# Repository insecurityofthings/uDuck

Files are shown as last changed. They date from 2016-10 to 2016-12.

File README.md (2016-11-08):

# μDuck

μDuck is stealth HID injector. It's a very small USB device that acts like a scripted keyboard. This can be used for automation and lulz, and has obvious security implications. It's quite similar in functionality to the [Hak5 Rubber Ducky](https://hakshop.com/products/usb-rubber-ducky-deluxe), and even uses the [same syntax](https://github.com/hak5darren/USB-Rubber-Ducky/wiki/Payloads) to define the scripted input.

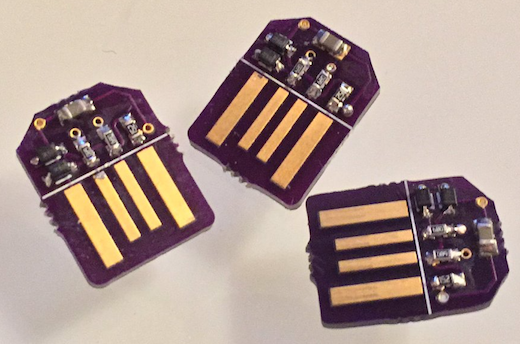
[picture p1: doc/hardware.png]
μDuck hardware


When μDuck is connected, it will wait 2 seconds in programming mode before switching to a keyboard. This is to allow the payload to be updated with the Python tool provided. It will wait 5 seconds before the first HID injection, then retry the payload automatically at 60 seconds, 5 minutes, and then every 4 hours with +/- 1 hour of random variance. This ensures reliable delivery, but expect that your payload may run more than once.

## Building a μDuck

The μDuck is quite inexpensive -- all the parts cost around $2 per unit. However, you will need some tools and know-how to get started. For more information, see the README file in the doc directory.

## Credits and License

The hardware is borrowed from [this blog](http://www.morethantechnical.com/2015/08/03/smallest-attiny45-usb/). The software is a modified version of "CapsLocker", which can be [found here](http://macetech.com/blog/?q=node/46). Our customized hardware design can be found in the "hardware" folder.

Our Python code and hardware design is MIT licensed. The USB firmware is licensed [according to the terms](https://www.obdev.at/products/vusb/license.html) of Objective Development's vUSB and GPLv2.

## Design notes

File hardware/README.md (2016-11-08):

Fixes
=====

- Schematic shows a 2k resistor. Use 1.5k instead.
- See [the documentation](https://github.com/phikshun/uDuck/tree/master/doc) for suggested parts.

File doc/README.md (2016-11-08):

# Building a μDuck

## Tools and Prerequisites

You'll need to following tools to construct the device:

- A decent temperature-controlled soldering iron with a fine point tip
- Solder (lead-free 0.8 mm)
- Flux with a fine-tip applicator
- Magnifying lamp
- A "third hand" tool
- Fine tweezers for handling SMT components
- An AVR programmer or a spare Arduino board
- A SOIC-8 clip for the programmer (not a hard requirement, but makes things much easier)

This project involves SMT soldering. You can find good tutorials [here](https://learn.adafruit.com/adafruit-guide-excellent-soldering/tools) and [here](https://www.sparkfun.com/tutorials/category/2). You'll need steady hands, good lighting, and magnification.

## Order Components

You can order the surface mount components from [DigiKey](http://www.digikey.com). You'll need the following components for each μDuck board:

- 1 x 0.1 uF ceramic capacitor [Link](http://www.digikey.ca/product-search/en?keywords=311-1141-1-ND)
- 2 x 68 Ohm resistors [Link](http://www.digikey.ca/product-search/en?keywords=P68GCT-ND)
- 2 x 3.6V zener diodes [Link](http://www.digikey.ca/product-search/en?keywords=MM3Z3V6T1GOSCT-ND)
- 1 x 1.5K Ohm resistor [Link](http://www.digikey.ca/product-search/en?keywords=311-1.5KGRCT-ND)
- 1 x Atmel ATTiny85 [Link](http://www.digikey.ca/product-search/en?keywords=ATTINY85-20SU-ND)

Note that you can swap components for similar parts with the same electrical properties and form factor.

In addition to the SMT parts, you will also need to get PCBs manufactured. There are many online services that allow you to submit designs and have them shipped to your door, even in fairly small quantities.

When submitting the hardware design, keep in mind the following:

- The board thickness should be 2.4mm. Typical PCB thickness (1.6mm) will fall right out of the port.
- Spring for gold plated pads - it will protect the USB pins from oxidation.

Unfortunately OSH Park cannot do 2.4mm boards, so we're using [AllPCB](http://www.allpcb.com) instead. If you have another preferred manufacturer, the results should be the same.

## Assembly

Use the hardware design files to show you where to place the parts. For IC and diode components, orientation is important. For passive components, they only need to be facing upwards.

Follow the tutorials on SMT soldering, or find a video on Youtube that demonstrates SMT soldering. Remember to use flux! :)

## Programming

There are two steps to programming. First, you'll need to get a bootloader on the microcontroller. Once the bootloader is installed you can upload new payloads with the `uduck_upload.py` script.

If you don't have a dedicated AVR programmer and would like to use an Arduino (this is how the Makefiles are currently setup), follow the instructions found [here](http://www.instructables.com/id/Turn-Your-Arduino-Into-an-ISP/).

### Bootloader Programming

You can find our slightly customized version of Micronucleus [here](https://github.com/phikshun/micronucleus). All we've done is configured the correct parameters in `firmware/configuration/t85_default/bootloaderconfig.h`, and updated the Makefile in `firmware/Makefile`.

To upload the bootloader, wire up a [SOIC-8 programming clip](https://www.amazon.com/Signstek-SOIC8-Socket-Adpter-Programmer/dp/B00V9QNAC4) to your AVR programmer and connect to the ATTiny85.

Now modify the following lines in the file `firmware/Makefile`:

Line 25: `PROGRAMMER ?= -c arduino`
- Leave as "arduino" or change to the correct programmer type

Line 29: `AVRDUDE = avrdude $(PROGRAMMER) -p $(DEVICE) -P /dev/cu.usbserial-A8008I9o -b 19200`
- Change the serial port and baud rate to the correct values. If you don't know what serial port your programmer is using, load the Arduino IDE and check.

To upload, you'll need `avrdude` installed. Sparkfun [has a tutorial](https://learn.sparkfun.com/tutorials/pocket-avr-programmer-hookup-guide/using-avrdude) that shows you the basics of AVRDUDE, which should be enough to get you up and running.

Once you have AVRDUDE working, open a shell, cd into the Micronucleus `firmware` directory and enter the commands:

`make fuse`

`make flash`

You don't need a full `avr-gcc` toolchain because we've precompiled the firmware for you. You're welcome to install an AVR toolchain and recompile. This will update the fuse settings on the ATTiny and program the bootloader in flash.

### Uploading the HID Injection Payload

To make it simple to update the μDuck payload, we've built a simple Python script. You will need to install the dependencies first using pip:

`pip install -r requirements.txt`

Before you start the programming tool, disconnect the μDuck from USB. The tool with prompt you when it's ready for the μDuck to be connected to USB.

The upload script takes only one parameter: the name of a file containing your Duckyscript. You can find some example scripts [here](https://github.com/hak5darren/USB-Rubber-Ducky/wiki/Payloads) if you need some inspiration.

Finally, run the command (where ducky.txt is the name of your Duckyscript file):

`./uduck_upload.py ducky.txt`

Your output should look similar to:

```
[+] Successfully compiled duckyscript
[+] Reading firmware image
[+] Patching firmware
[+] Successfully patched firmware

[+] Please plug in your uDuck device...
Press Ctrl-C to terminate the program...
[+] Device found:
      Available space for user applications: 6522 bytes
      Suggested sleep time between sending pages: 5 ms
      Whole page count: 102 page size: 64
      Erase function sleep duration: 510 ms

[+] Erasing flash...
[====================================================================] 100%
[+] Starting upload...
[====================================================================] 100%
[+] Upload finished. Enjoy! ;)
```

Plug-in your device when prompted. As indicated by the output above, the script is byte patching the compiled Duckyscript into the firmware hex file dynamically, then uploading it to the bootloader. We think that's pretty neat.

If you experience an error, let us know by submitting an issue. We will try to assist if time permits.

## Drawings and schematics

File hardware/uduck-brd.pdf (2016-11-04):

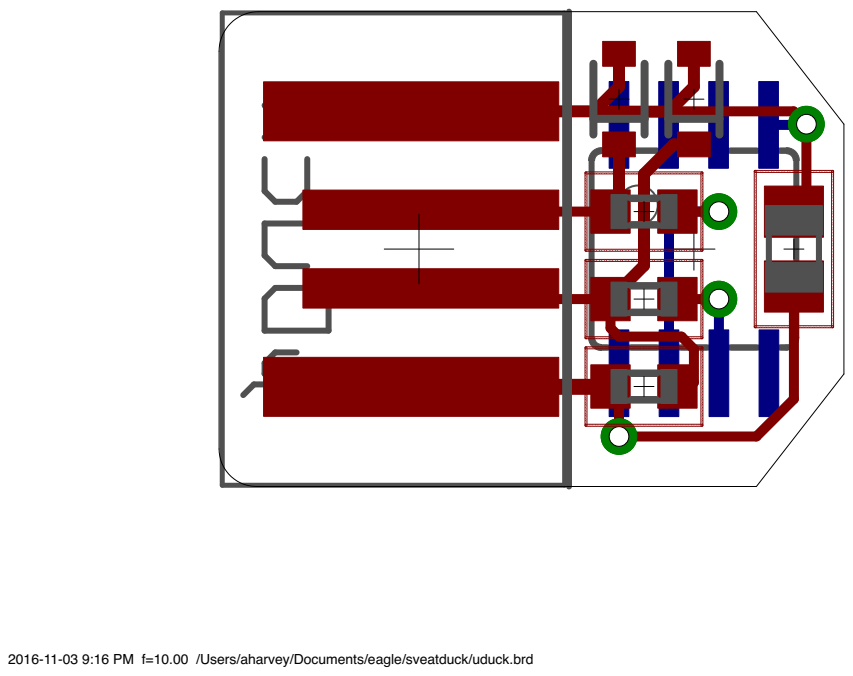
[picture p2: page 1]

2016-11-03 9:16 PM f=10.00 /Users/aharvey/Documents/eagle/sveatduck/uduck.brd

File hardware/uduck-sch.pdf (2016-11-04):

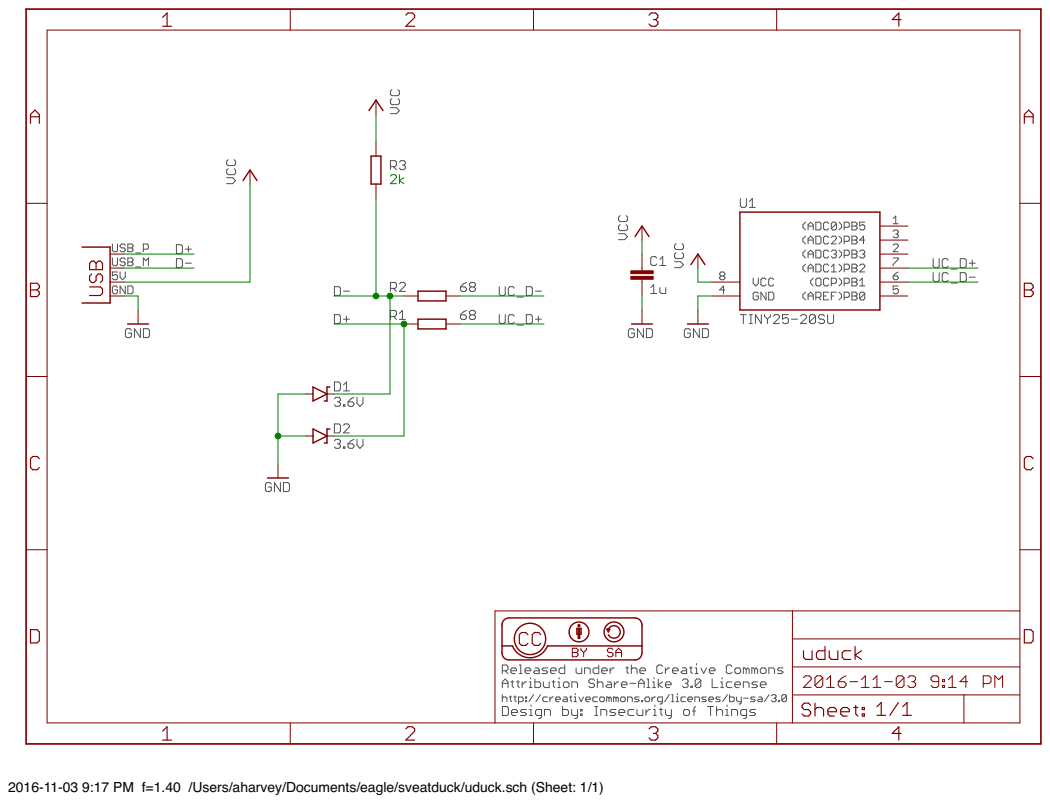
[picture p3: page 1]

2016-11-03 9:17 PM f=1.40 /Users/aharvey/Documents/eagle/sveatduck/uduck.sch (Sheet: 1/1)

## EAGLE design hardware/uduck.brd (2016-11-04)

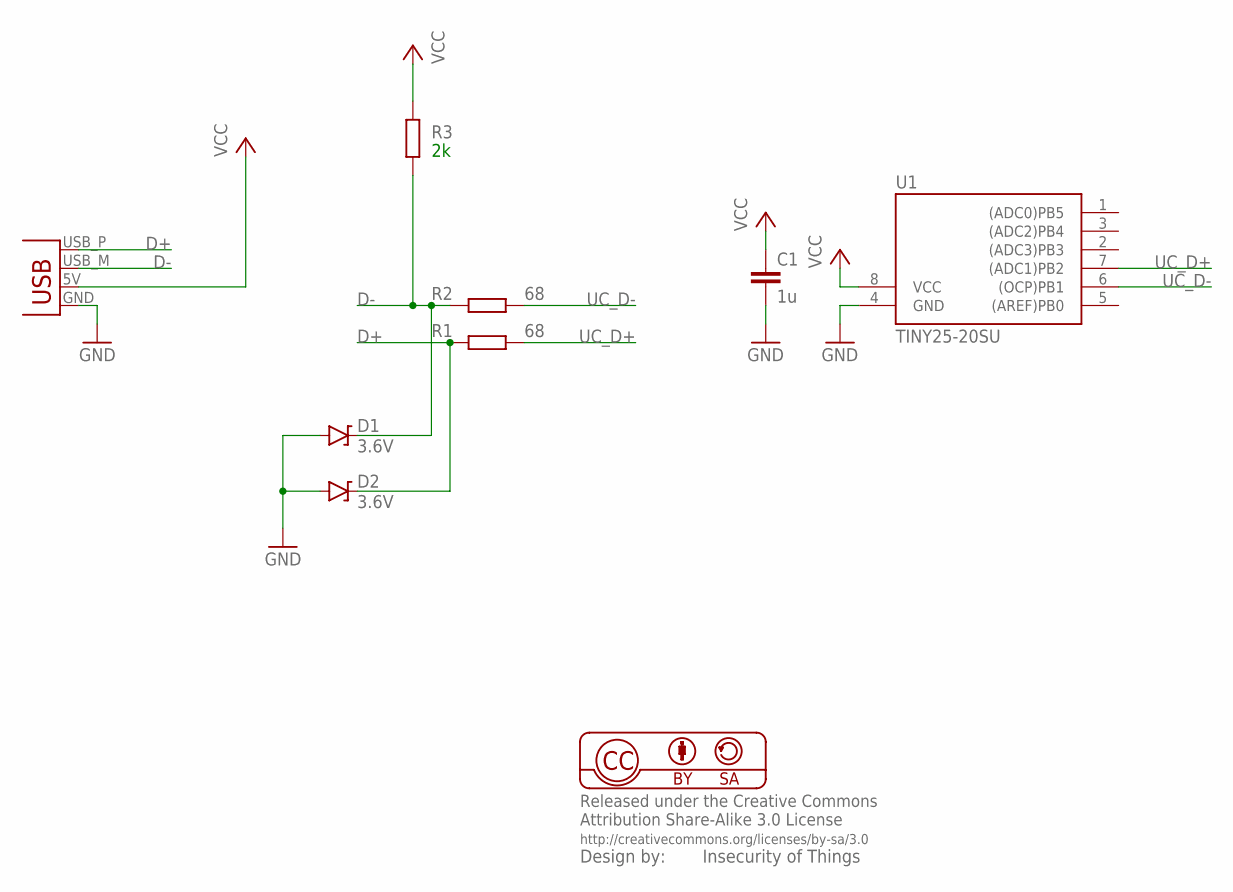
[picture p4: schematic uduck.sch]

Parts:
C1: 1u; C0805
D1, D2: 3.6V; SOD-323
R1, R2: 68; R0603
R3: 2k; R0603
U1: TINY25-20SU; SOIC8
X1: USBPCB; USB-A-PCB

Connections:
D+: D2.C, R1.2, X1.USB_P (D+)
D-: D1.C, R2.2, R3.1, X1.USB_M (D-)
GND: C1.2, D1.A, D2.A, U1.4 (GND), X1.GND
UC_D+: R1.1, U1.7 ((ADC1)PB2)
UC_D-: R2.1, U1.6 ((OCP)PB1)
VCC: C1.1, R3.2, U1.8 (VCC), X1.5V (VBUS)

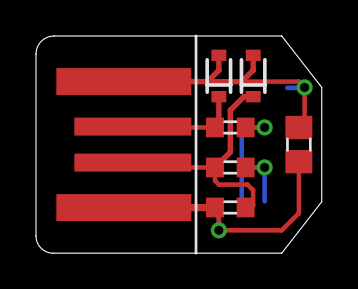
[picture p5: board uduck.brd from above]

Board: 2 copper layers, 15.9 x 12.1 mm, 8 parts (1 on the bottom side), 6 nets.

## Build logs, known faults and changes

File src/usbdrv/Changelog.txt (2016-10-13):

This file documents changes in the firmware-only USB driver for atmel's AVR
microcontrollers. New entries are always appended to the end of the file.
Scroll down to the bottom to see the most recent changes.

2005-04-01:
  - Implemented endpoint 1 as interrupt-in endpoint.
  - Moved all configuration options to usbconfig.h which is not part of the
    driver.
  - Changed interface for usbVendorSetup().
  - Fixed compatibility with ATMega8 device.
  - Various minor optimizations.

2005-04-11:
  - Changed interface to application: Use usbFunctionSetup(), usbFunctionRead()
    and usbFunctionWrite() now. Added configuration options to choose which
    of these functions to compile in.
  - Assembler module delivers receive data non-inverted now.
  - Made register and bit names compatible with more AVR devices.

2005-05-03:
  - Allow address of usbRxBuf on any memory page as long as the buffer does
    not cross 256 byte page boundaries.
  - Better device compatibility: works with Mega88 now.
  - Code optimization in debugging module.
  - Documentation updates.

2006-01-02:
  - Added (free) default Vendor- and Product-IDs bought from voti.nl.
  - Added USBID-License.txt file which defines the rules for using the free
    shared VID/PID pair.
  - Added Readme.txt to the usbdrv directory which clarifies administrative
    issues.

2006-01-25:
  - Added "configured state" to become more standards compliant.
  - Added "HALT" state for interrupt endpoint.
  - Driver passes the "USB Command Verifier" test from usb.org now.
  - Made "serial number" a configuration option.
  - Minor optimizations, we now recommend compiler option "-Os" for best
    results.
  - Added a version number to usbdrv.h

2006-02-03:
  - New configuration variable USB_BUFFER_SECTION for the memory section where
    the USB rx buffer will go. This defaults to ".bss" if not defined. Since
    this buffer MUST NOT cross 256 byte pages (not even touch a page at the
    end), the user may want to pass a linker option similar to
    "-Wl,--section-start=.mybuffer=0x800060".
  - Provide structure for usbRequest_t.
  - New defines for USB constants.
  - Prepared for HID implementations.
  - Increased data size limit for interrupt transfers to 8 bytes.
  - New macro usbInterruptIsReady() to query interrupt buffer state.

2006-02-18:
  - Ensure that the data token which is sent as an ack to an OUT transfer is
    always zero sized. This fixes a bug where the host reports an error after
    sending an out transfer to the device, although all data arrived at the
    device.
  - Updated docs in usbdrv.h to reflect changed API in usbFunctionWrite().

* Release 2006-02-20

  - Give a compiler warning when compiling with debugging turned on.
  - Added Oleg Semyonov's changes for IAR-cc compatibility.
  - Added new (optional) functions usbDeviceConnect() and usbDeviceDisconnect()
    (also thanks to Oleg!).
  - Rearranged tests in usbPoll() to save a couple of instructions in the most
    likely case that no actions are pending.
  - We need a delay between the SET ADDRESS request until the new address
    becomes active. This delay was handled in usbPoll() until now. Since the
    spec says that the delay must not exceed 2ms, previous versions required
    aggressive polling during the enumeration phase. We have now moved the
    handling of the delay into the interrupt routine.
  - We must not reply with NAK to a SETUP transaction. We can only achieve this
    by making sure that the rx buffer is empty when SETUP tokens are expected.
    We therefore don't pass zero sized data packets from the status phase of
    a transfer to usbPoll(). This change MAY cause troubles if you rely on
    receiving a less than 8 bytes long packet in usbFunctionWrite() to
    identify the end of a transfer. usbFunctionWrite() will NEVER be called
    with a zero length.

* Release 2006-03-14

  - Improved IAR C support: tiny memory model, more devices
  - Added template usbconfig.h file under the name usbconfig-prototype.h

* Release 2006-03-26

  - Added provision for one more interrupt-in endpoint (endpoint 3).
  - Added provision for one interrupt-out endpoint (endpoint 1).
  - Added flowcontrol macros for USB.
  - Added provision for custom configuration descriptor.
  - Allow ANY two port bits for D+ and D-.
  - Merged (optional) receive endpoint number into global usbRxToken variable.
  - Use USB_CFG_IOPORTNAME instead of USB_CFG_IOPORT. We now construct the
    variable name from the single port letter instead of computing the address
    of related ports from the output-port address.

* Release 2006-06-26

  - Updated documentation in usbdrv.h and usbconfig-prototype.h to reflect the
    new features.
  - Removed "#warning" directives because IAR does not understand them. Use
    unused static variables instead to generate a warning.
  - Do not include <avr/io.h> when compiling with IAR.
  - Introduced USB_CFG_DESCR_PROPS_* in usbconfig.h to configure how each
    USB descriptor should be handled. It is now possible to provide descriptor
    data in Flash, RAM or dynamically at runtime.
  - STALL is now a status in usbTxLen* instead of a message. We can now conform
    to the spec and leave the stall status pending until it is cleared.
  - Made usbTxPacketCnt1 and usbTxPacketCnt3 public. This allows the
    application code to reset data toggling on interrupt pipes.

* Release 2006-07-18

  - Added an #if !defined __ASSEMBLER__ to the warning in usbdrv.h. This fixes
    an assembler error.
  - usbDeviceDisconnect() takes pull-up resistor to high impedance now.

* Release 2007-02-01

  - Merged in some code size improvements from usbtiny (thanks to Dick
    Streefland for these optimizations!)
  - Special alignment requirement for usbRxBuf not required any more. Thanks
    again to Dick Streefland for this hint!
  - Reverted to "#warning" instead of unused static variables -- new versions
    of IAR CC should handle this directive.
  - Changed Open Source license to GNU GPL v2 in order to make linking against
    other free libraries easier. We no longer require publication of the
    circuit diagrams, but we STRONGLY encourage it. If you improve the driver
    itself, PLEASE grant us a royalty free license to your changes for our
    commercial license.

* Release 2007-03-29

  - New configuration option "USB_PUBLIC" in usbconfig.h.
  - Set USB version number to 1.10 instead of 1.01.
  - Code used USB_CFG_DESCR_PROPS_STRING_DEVICE and
    USB_CFG_DESCR_PROPS_STRING_PRODUCT inconsistently. Changed all occurrences
    to USB_CFG_DESCR_PROPS_STRING_PRODUCT.
  - New assembler module for 16.5 MHz RC oscillator clock with PLL in receiver
    code.
  - New assembler module for 16 MHz crystal.
  - usbdrvasm.S contains common code only, clock-specific parts have been moved
    to usbdrvasm12.S, usbdrvasm16.S and usbdrvasm165.S respectively.

* Release 2007-06-25

  - 16 MHz module: Do SE0 check in stuffed bits as well.

* Release 2007-07-07

  - Define hi8(x) for IAR compiler to limit result to 8 bits. This is necessary
    for negative values.
  - Added 15 MHz module contributed by V. Bosch.
  - Interrupt vector name can now be configured. This is useful if somebody
    wants to use a different hardware interrupt than INT0.

* Release 2007-08-07

  - Moved handleIn3 routine in usbdrvasm16.S so that relative jump range is
    not exceeded.
  - More config options: USB_RX_USER_HOOK(), USB_INITIAL_DATATOKEN,
    USB_COUNT_SOF
  - USB_INTR_PENDING can now be a memory address, not just I/O

* Release 2007-09-19

  - Split out common parts of assembler modules into separate include file
  - Made endpoint numbers configurable so that given interface definitions
    can be matched. See USB_CFG_EP3_NUMBER in usbconfig-prototype.h.
  - Store endpoint number for interrupt/bulk-out so that usbFunctionWriteOut()
    can handle any number of endpoints.
  - Define usbDeviceConnect() and usbDeviceDisconnect() even if no
    USB_CFG_PULLUP_IOPORTNAME is defined. Directly set D+ and D- to 0 in this
    case.

* Release 2007-12-01

  - Optimize usbDeviceConnect() and usbDeviceDisconnect() for less code size
    when USB_CFG_PULLUP_IOPORTNAME is not defined.

* Release 2007-12-13

  - Renamed all include-only assembler modules from *.S to *.inc so that
    people don't add them to their project sources.
  - Distribute leap bits in tx loop more evenly for 16 MHz module.
  - Use "macro" and "endm" instead of ".macro" and ".endm" for IAR
  - Avoid compiler warnings for constant expr range by casting some values in
    USB descriptors.

* Release 2008-01-21

  - Fixed bug in 15 and 16 MHz module where the new address set with
    SET_ADDRESS was already accepted at the next NAK or ACK we send, not at
    the next data packet we send. This caused problems when the host polled
    too fast. Thanks to Alexander Neumann for his help and patience debugging
    this issue!

* Release 2008-02-05

  - Fixed bug in 16.5 MHz module where a register was used in the interrupt
    handler before it was pushed. This bug was introduced with version
    2007-09-19 when common parts were moved to a separate file.
  - Optimized CRC routine (thanks to Reimar Doeffinger).

* Release 2008-02-16

  - Removed outdated IAR compatibility stuff (code sections).
  - Added hook macros for USB_RESET_HOOK() and USB_SET_ADDRESS_HOOK().
  - Added optional routine usbMeasureFrameLength() for calibration of the
    internal RC oscillator.

* Release 2008-02-28

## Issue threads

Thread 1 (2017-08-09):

Problem with uploading!

detectingdragon77, 2017-08-09:
user$ python uduck_upload.py youtube-blaster.txt
CAN'T PROCESS... REM Author: Cody Theodore
CAN'T PROCESS... REM Title: OSX Youtube Blast
CAN'T PROCESS... REM This payload will open terminal, crank up the Macs volume all the way, then open a youtube video of
CAN'T PROCESS... REM your choice by replacing the link.
[+] Successfully compiled duckyscript
[+] Reading firmware image
[+] Patching firmware
[+] Successfully patched firmware

[+] Please plug in your uDuck device...
Press Ctrl-C to terminate the program...

Traceback (most recent call last):
  File "uduck_upload.py", line 414, in <module>
    mn.connect()
  File "uduck_upload.py", line 237, in connect
    self.flash_size, self.page_size, buf3, self.signature = struct.unpack('>HBBH', ret)
struct.error: unpack requires a string argument of length 6
user$

Help please

gloglas, 2017-11-14:
Help please too

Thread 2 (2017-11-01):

digispark-tiny

tonyputi, 2017-11-01:
Hi! congratulation for your amazing work but it is possible to port it to a digispark-tiny device?
I've seen that your hardware use different pins on the attiny and should be not enough to change it in usbconfig.h

Could you help me please?

Regards

phikshun, 2017-11-05:
It doesn't really need to be ported. uDuck and the Digispark are both ATTiny85 based. Only a few changes are required.

In usbconfig.h, change the pin assignments to the following:

```
#define USB_CFG_DMINUS_BIT      3
#define USB_CFG_DPLUS_BIT       4
```

The go into src/build and edit the Makefile:

```
BURNPROGRAMMER = arduino
BURNPORT = /dev/cu.usbserial-A8008I9o
```

You'll need to change those lines if you're using a different programmer. I was using an Arduino as ISP.

After you install avrdude and the avr toolchain, connect the JP3 header to your programmer and run `make clean`, `make all`, and finally `make install`.

After the initial install you'll be able to use the `uduck_upload.py` script to upload new payloads.

tonyputi, 2017-11-06:
Hi and thank you for your reply but after your changes nothing happens

Here my dmesg output:
```
[84243.508399] usb 2-2: new low-speed USB device number 18 using xhci_hcd
[84243.632445] usb 2-2: device descriptor read/64, error -71
[84243.864443] usb 2-2: device descriptor read/64, error -71
[84244.092393] usb 2-2: new low-speed USB device number 19 using xhci_hcd
[84244.216442] usb 2-2: device descriptor read/64, error -71
[84244.448428] usb 2-2: device descriptor read/64, error -71
[84244.676380] usb 2-2: new low-speed USB device number 20 using xhci_hcd
[84244.676808] usb 2-2: Device not responding to setup address.
[84244.884836] usb 2-2: Device not responding to setup address.
[84245.092372] usb 2-2: device not accepting address 20, error -71
[84245.212377] usb 2-2: new low-speed USB device number 21 using xhci_hcd
[84245.212798] usb 2-2: Device not responding to setup address.
[84245.420846] usb 2-2: Device not responding to setup address.
[84245.628346] usb 2-2: device not accepting address 21, error -71

```

Any other suggest?

Regards

CriJonsi, 2018-01-19:
Hi!
You should read this article which use the digispark-tiny device and put micronucleus on it. He explain everything:
https://medium.com/@_MG_/mr-self-destruct-7986998f32a8

Regards

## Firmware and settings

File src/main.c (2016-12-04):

#include <avr/io.h>
#include <avr/wdt.h>
#include <avr/eeprom.h>
#include <avr/interrupt.h>
#include <avr/pgmspace.h>
#include <util/delay.h>
#include <stdlib.h>

#include "usbdrv.h"
#include "oddebug.h"

static uchar reportBuffer[2];    // buffer for HID reports
static uchar idleRate;           // in 4 ms units
static uchar reportCount = 0;    // current report
static unsigned long TimerDelay;  // counter for delay period
static unsigned int index = 0;   // index into attack buffer
static unsigned int attempt = 0; // track attempts for backoff interval

// attack buffer will be byte-patched here
// stored in modifier, hid code, delay value format
PROGMEM const uchar attack[] = {
    0x44, 0x43, 0x42, 0x41, 0x41, 0x41, 0x41, 0x41, 0x41, 0x41,
    0x41, 0x41, 0x41, 0x41, 0x41, 0x41, 0x41, 0x41, 0x41, 0x41,
    0x41, 0x41, 0x41, 0x41, 0x41, 0x41, 0x41, 0x41, 0x41, 0x41,
    0x41, 0x41, 0x41, 0x41, 0x41, 0x41, 0x41, 0x41, 0x41, 0x41,
    0x41, 0x41, 0x41, 0x41, 0x41, 0x41, 0x41, 0x41, 0x41, 0x41,
    0x41, 0x41, 0x41, 0x41, 0x41, 0x41, 0x41, 0x41, 0x41, 0x41,
    0x41, 0x41, 0x41, 0x41, 0x41, 0x41, 0x41, 0x41, 0x41, 0x41,
    0x41, 0x41, 0x41, 0x41, 0x41, 0x41, 0x41, 0x41, 0x41, 0x41,
    0x41, 0x41, 0x41, 0x41, 0x41, 0x41, 0x41, 0x41, 0x41, 0x41,
    0x41, 0x41, 0x41, 0x41, 0x41, 0x41, 0x41, 0x41, 0x41, 0x41,
    0x41, 0x41, 0x41, 0x41, 0x41, 0x41, 0x41, 0x41, 0x41, 0x41,
    0x41, 0x41, 0x41, 0x41, 0x41, 0x41, 0x41, 0x41, 0x41, 0x41,
    0x41, 0x41, 0x41, 0x41, 0x41, 0x41, 0x41, 0x41, 0x41, 0x41,
    0x41, 0x41, 0x41, 0x41, 0x41, 0x41, 0x41, 0x41, 0x41, 0x41,
    0x41, 0x41, 0x41, 0x41, 0x41, 0x41, 0x41, 0x41, 0x41, 0x41,
    0x41, 0x41, 0x41, 0x41, 0x41, 0x41, 0x41, 0x41, 0x41, 0x41,
    0x41, 0x41, 0x41, 0x41, 0x41, 0x41, 0x41, 0x41, 0x41, 0x41,
    0x41, 0x41, 0x41, 0x41, 0x41, 0x41, 0x41, 0x41, 0x41, 0x41,
    0x41, 0x41, 0x41, 0x41, 0x41, 0x41, 0x41, 0x41, 0x41, 0x41,
    0x41, 0x41, 0x41, 0x41, 0x41, 0x41, 0x41, 0x41, 0x41, 0x41,
    0x41, 0x41, 0x41, 0x41, 0x41, 0x41, 0x41, 0x41, 0x41, 0x41,
    0x41, 0x41, 0x41, 0x41, 0x41, 0x41, 0x41, 0x41, 0x41, 0x41,
    0x41, 0x41, 0x41, 0x41, 0x41, 0x41, 0x41, 0x41, 0x41, 0x41,
    0x41, 0x41, 0x41, 0x41, 0x41, 0x41, 0x41, 0x41, 0x41, 0x41,
    0x41, 0x41, 0x41, 0x41, 0x41, 0x41, 0x41, 0x41, 0x41, 0x41,
    0x41, 0x41, 0x41, 0x41, 0x41, 0x41, 0x41, 0x41, 0x41, 0x41,
    0x41, 0x41, 0x41, 0x41, 0x41, 0x41, 0x41, 0x41, 0x41, 0x41,
    0x41, 0x41, 0x41, 0x41, 0x41, 0x41, 0x41, 0x41, 0x41, 0x41,
    0x41, 0x41, 0x41, 0x41, 0x41, 0x41, 0x41, 0x41, 0x41, 0x41,
    0x41, 0x41, 0x41, 0x41, 0x41, 0x41, 0x41, 0x41, 0x41, 0x41,
    0x41, 0x41, 0x41, 0x41, 0x41, 0x41, 0x41, 0x41, 0x41, 0x41,
    0x41, 0x41, 0x41, 0x41, 0x41, 0x41, 0x41, 0x41, 0x41, 0x41,
    0x41, 0x41, 0x41, 0x41, 0x41, 0x41, 0x41, 0x41, 0x41, 0x41,
    0x41, 0x41, 0x41, 0x41, 0x41, 0x41, 0x41, 0x41, 0x41, 0x41,
    0x41, 0x41, 0x41, 0x41, 0x41, 0x41, 0x41, 0x41, 0x41, 0x41,
    0x41, 0x41, 0x41, 0x41, 0x41, 0x41, 0x41, 0x41, 0x41, 0x41,
    0x41, 0x41, 0x41, 0x41, 0x41, 0x41, 0x41, 0x41, 0x41, 0x41,
    0x41, 0x41, 0x41, 0x41, 0x41, 0x41, 0x41, 0x41, 0x41, 0x41,
    0x41, 0x41, 0x41, 0x41, 0x41, 0x41, 0x41, 0x41, 0x41, 0x41,
    0x41, 0x41, 0x41, 0x41, 0x41, 0x41, 0x41, 0x41, 0x41, 0x41,
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
};

PROGMEM const char usbHidReportDescriptor[USB_CFG_HID_REPORT_DESCRIPTOR_LENGTH] = { // USB report descriptor
    0x05, 0x01,                    // USAGE_PAGE (Generic Desktop)
    0x09, 0x06,                    // USAGE (Keyboard)
    0xa1, 0x01,                    // COLLECTION (Application)
    0x05, 0x07,                    //   USAGE_PAGE (Keyboard)
    0x19, 0xe0,                    //   USAGE_MINIMUM (Keyboard LeftControl)
    0x29, 0xe7,                    //   USAGE_MAXIMUM (Keyboard Right GUI)
    0x15, 0x00,                    //   LOGICAL_MINIMUM (0)
    0x25, 0x01,                    //   LOGICAL_MAXIMUM (1)
    0x75, 0x01,                    //   REPORT_SIZE (1)
    0x95, 0x08,                    //   REPORT_COUNT (8)
    0x81, 0x02,                    //   INPUT (Data,Var,Abs)
    0x95, 0x01,                    //   REPORT_COUNT (1)
    0x75, 0x08,                    //   REPORT_SIZE (8)
    0x25, 0x65,                    //   LOGICAL_MAXIMUM (101)
    0x19, 0x00,                    //   USAGE_MINIMUM (Reserved (no event indicated))
    0x29, 0x65,                    //   USAGE_MAXIMUM (Keyboard Application)
    0x81, 0x00,                    //   INPUT (Data,Ary,Abs)
    0xc0                           // END_COLLECTION
};
/* We use a simplifed keyboard report descriptor which does not support the
 * boot protocol. We don't allow setting status LEDs and we only allow one
 * simultaneous key press (except modifiers). We can therefore use short
 * 2 byte input reports.
 * The report descriptor has been created with usb.org's "HID Descriptor Tool"
 * which can be downloaded from http://www.usb.org/developers/hidpage/.
 * Redundant entries (such as LOGICAL_MINIMUM and USAGE_PAGE) have been omitted
 * for the second INPUT item.
 */

static void buildReport(uchar mod, uchar key)
{
    reportCount++;
    reportBuffer[0] = mod;
    reportBuffer[1] = key;
}


static void timerPoll(void)
{
    static unsigned int timerCnt;

    if (TIFR & (1 << TOV1)) {
        TIFR = (1 << TOV1); // clear overflow
        if (++timerCnt >= TimerDelay) { // check for end of delay
            TimerDelay = 1; // TimerDelay of 1 signals start
                            // of next keystroke injection
            timerCnt = 0;
        }
    }
}

static void timerInit(void)
{
    TCCR1 = 0x0b; // select clock: 16.5M/1k -> overflow rate = 16.5M/256k = 62.94 Hz
}

uchar usbFunctionSetup(uchar data[8])
{
    usbRequest_t *rq = (void *)data;

    usbMsgPtr = reportBuffer;
    if ((rq->bmRequestType & USBRQ_TYPE_MASK) == USBRQ_TYPE_CLASS) { // class request type
        if (rq->bRequest == USBRQ_HID_GET_REPORT) { // wValue: ReportType (highbyte), ReportID (lowbyte)
            // we only have one report type, so don't look at wValue
            buildReport(0, 0);
            return sizeof(reportBuffer);
        } else if (rq->bRequest == USBRQ_HID_GET_IDLE) {
            usbMsgPtr = &idleRate;
            return 1;
        } else if(rq->bRequest == USBRQ_HID_SET_IDLE) {
            idleRate = rq->wValue.bytes[1];
        }
    } else {
        /* no vendor specific requests implemented */
    }
    return 0;
}

/* Calibrate the RC oscillator to 8.25 MHz. The core clock of 16.5 MHz is
 * derived from the 66 MHz peripheral clock by dividing. Our timing reference
 * is the Start Of Frame signal (a single SE0 bit) available immediately after
 * a USB RESET. We first do a binary search for the OSCCAL value and then
 * optimize this value with a neighboorhod search.
 * This algorithm may also be used to calibrate the RC oscillator directly to
 * 12 MHz (no PLL involved, can therefore be used on almost ALL AVRs), but this
 * is wide outside the spec for the OSCCAL value and the required precision for
 * the 12 MHz clock! Use the RC oscillator calibrated to 12 MHz for
 * experimental purposes only!
 */
static void calibrateOscillator(void)
{
    uchar step = 128;
    uchar trialValue = 0, optimumValue;
    int x, optimumDev, targetValue = (unsigned)(1499 * (double)F_CPU / 10.5e6 + 0.5);

    // do a binary search:
    do {
        OSCCAL = trialValue + step;
        x = usbMeasureFrameLength();    // proportional to current real frequency
        if(x < targetValue)             // frequency still too low
            trialValue += step;
        step >>= 1;
    } while(step > 0);

    /* We have a precision of +/- 1 for optimum OSCCAL here */
    /* now do a neighborhood search for optimum value */
    optimumValue = trialValue;
    optimumDev = x; // this is certainly far away from optimum
    for (OSCCAL = trialValue - 1; OSCCAL <= trialValue + 1; OSCCAL++) {
        x = usbMeasureFrameLength() - targetValue;
        if (x < 0)
            x = -x;
        if (x < optimumDev) {
            optimumDev = x;
            optimumValue = OSCCAL;
        }
    }
    OSCCAL = optimumValue;
}
/*
Note: This calibration algorithm may try OSCCAL values of up to 192 even if
the optimum value is far below 192. It may therefore exceed the allowed clock
frequency of the CPU in low voltage designs!
You may replace this search algorithm with any other algorithm you like if
you have additional constraints such as a maximum CPU clock.
For version 5.x RC oscillators (those with a split range of 2x128 steps, e.g.
ATTiny25, ATTiny45, ATTiny85), it may be useful to search for the optimum in
both regions.
*/

void usbEventResetReady(void)
{
    calibrateOscillator();
    eeprom_write_byte(0, OSCCAL); // store the calibrated value in EEPROM
}

int main(void)
{
    uchar i;
    uchar calibrationValue;
    uchar mod, hid, delay;

    calibrationValue = eeprom_read_byte(0); // calibration value from last time
    
    if(calibrationValue != 0xff) {
        OSCCAL = calibrationValue;
    }
    
    odDebugInit();
    usbDeviceDisconnect();
    
    for (i = 0; i < 20; i++) {  // 300 ms disconnect
        _delay_ms(15);
    }

    usbDeviceConnect();

    wdt_enable(WDTO_1S);
    timerInit();
    TimerDelay = 315; // initial 5 second delay

    usbInit();
    sei();

    for (;;) {    // main event loop
        wdt_reset();
        usbPoll();

        if (usbInterruptIsReady() && TimerDelay == 1) {

            // get the values for the modifier key, hid code, and delay value 
            // from the attack array
            mod   = pgm_read_byte(&(attack[index]));
            hid   = pgm_read_byte(&(attack[index + 1]));
            delay = pgm_read_byte(&(attack[index + 2]));

            // if all three values are 0x41 we've hit the end of the attack
            // array
            if (mod == 0x41 && hid == 0x41 && delay == 0x41) {
                // send keyup event
                buildReport(0, 0);
                usbSetInterrupt(reportBuffer, sizeof(reportBuffer));
                
                // reset attack index and reportCount variables
                index = 0;
                reportCount = 0;
                // setup for next delay value
                if (attempt == 0) {
                    TimerDelay = 3780; // 60 seconds for second attempt
                    attempt++;
                } else if (attempt == 1) {
                    TimerDelay = 18900; // 5 mins for third attempt
                    attempt++;
                } else {
                    TimerDelay = 907200 + rand() * 8; // 4 hours + 0...64 minutes
                }
            } else if (reportCount & 1) {
                // if reportCount is odd, send keyup event
                buildReport(0, 0);
                usbSetInterrupt(reportBuffer, sizeof(reportBuffer));
            } else {
                // transmit modifier and hid code from attack array
                // on even reportCount values
                buildReport(mod, hid);
                usbSetInterrupt(reportBuffer, sizeof(reportBuffer));
                
                // insert delay if present
                if (delay) {
                    TimerDelay = delay + 1;
                }
                // advance to next triplet
                index += 3;
            }
        }
        
        // service timer
        timerPoll();
    }
    return 0;
}

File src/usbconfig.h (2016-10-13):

/* Name: usbconfig.h
 * Project: AVR USB driver
 * Author: Christian Starkjohann
 * Creation Date: 2007-06-23
 * Tabsize: 4
 * Copyright: (c) 2007 by OBJECTIVE DEVELOPMENT Software GmbH
 * License: GNU GPL v2 (see License.txt) or proprietary (CommercialLicense.txt)
 * This Revision: $Id: usbconfig.h 537 2008-02-28 21:13:01Z cs $
 */

#ifndef __usbconfig_h_included__
#define __usbconfig_h_included__

/* ---------------------------- Hardware Config ---------------------------- */

#define USB_CFG_IOPORTNAME      B
/* This is the port where the USB bus is connected. When you configure it to
 * "B", the registers PORTB, PINB and DDRB will be used.
 */
#define USB_CFG_DMINUS_BIT      1
/* This is the bit number in USB_CFG_IOPORT where the USB D- line is connected.
 * This may be any bit in the port.
 */
#define USB_CFG_DPLUS_BIT       2
/* This is the bit number in USB_CFG_IOPORT where the USB D+ line is connected.
 * This may be any bit in the port. Please note that D+ must also be connected
 * to interrupt pin INT0!
 */
#define USB_CFG_CLOCK_KHZ       (F_CPU/1000)
/* Clock rate of the AVR in MHz. Legal values are 12000, 16000 or 16500.
 * The 16.5 MHz version of the code requires no crystal, it tolerates +/- 1%
 * deviation from the nominal frequency. All other rates require a precision
 * of 2000 ppm and thus a crystal!
 * Default if not specified: 12 MHz
 */

/* ----------------------- Optional Hardware Config ------------------------ */

/* #define USB_CFG_PULLUP_IOPORTNAME   D */
/* If you connect the 1.5k pullup resistor from D- to a port pin instead of
 * V+, you can connect and disconnect the device from firmware by calling
 * the macros usbDeviceConnect() and usbDeviceDisconnect() (see usbdrv.h).
 * This constant defines the port on which the pullup resistor is connected.
 */
/* #define USB_CFG_PULLUP_BIT          4 */
/* This constant defines the bit number in USB_CFG_PULLUP_IOPORT (defined
 * above) where the 1.5k pullup resistor is connected. See description
 * above for details.
 */

/* --------------------------- Functional Range ---------------------------- */

#define USB_CFG_HAVE_INTRIN_ENDPOINT    1
/* Define this to 1 if you want to compile a version with two endpoints: The
 * default control endpoint 0 and an interrupt-in endpoint 1.
 */
#define USB_CFG_HAVE_INTRIN_ENDPOINT3   0
/* Define this to 1 if you want to compile a version with three endpoints: The
 * default control endpoint 0, an interrupt-in endpoint 1 and an interrupt-in
 * endpoint 3. You must also enable endpoint 1 above.
 */
#define USB_CFG_IMPLEMENT_HALT          0
/* Define this to 1 if you also want to implement the ENDPOINT_HALT feature
 * for endpoint 1 (interrupt endpoint). Although you may not need this feature,
 * it is required by the standard. We have made it a config option because it
 * bloats the code considerably.
 */
#define USB_CFG_INTR_POLL_INTERVAL      10
/* If you compile a version with endpoint 1 (interrupt-in), this is the poll
 * interval. The value is in milliseconds and must not be less than 10 ms for
 * low speed devices.
 */
#define USB_CFG_IS_SELF_POWERED         0
/* Define this to 1 if the device has its own power supply. Set it to 0 if the
 * device is powered from the USB bus.
 */
#define USB_CFG_MAX_BUS_POWER           50
/* Set this variable to the maximum USB bus power consumption of your device.
 * The value is in milliamperes. [It will be divided by two since USB
 * communicates power requirements in units of 2 mA.]
 */
#define USB_CFG_IMPLEMENT_FN_WRITE      0
/* Set this to 1 if you want usbFunctionWrite() to be called for control-out
 * transfers. Set it to 0 if you don't need it and want to save a couple of
 * bytes.
 */
#define USB_CFG_IMPLEMENT_FN_READ       0
/* Set this to 1 if you need to send control replies which are generated
 * "on the fly" when usbFunctionRead() is called. If you only want to send
 * data from a static buffer, set it to 0 and return the data from
 * usbFunctionSetup(). This saves a couple of bytes.
 */
#define USB_CFG_IMPLEMENT_FN_WRITEOUT   0
/* Define this to 1 if you want to use interrupt-out (or bulk out) endpoint 1.
 * You must implement the function usbFunctionWriteOut() which receives all
 * interrupt/bulk data sent to endpoint 1.
 */
#define USB_CFG_HAVE_FLOWCONTROL        0
/* Define this to 1 if you want flowcontrol over USB data. See the definition
 * of the macros usbDisableAllRequests() and usbEnableAllRequests() in
 * usbdrv.h.
 */
#ifndef __ASSEMBLER__
extern void usbEventResetReady(void);
#endif
#define USB_RESET_HOOK(isReset)             if(!isReset){usbEventResetReady();}
/* This macro is a hook if you need to know when an USB RESET occurs. It has
 * one parameter which distinguishes between the start of RESET state and its
 * end.
 */
#define USB_CFG_HAVE_MEASURE_FRAME_LENGTH   1
/* define this macro to 1 if you want the function usbMeasureFrameLength()
 * compiled in. This function can be used to calibrate the AVR's RC oscillator.
 */
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

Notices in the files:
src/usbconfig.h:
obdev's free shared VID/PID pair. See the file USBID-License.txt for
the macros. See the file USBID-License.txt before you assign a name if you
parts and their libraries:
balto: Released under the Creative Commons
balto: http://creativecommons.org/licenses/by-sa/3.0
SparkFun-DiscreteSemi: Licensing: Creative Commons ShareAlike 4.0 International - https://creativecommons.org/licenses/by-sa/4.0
